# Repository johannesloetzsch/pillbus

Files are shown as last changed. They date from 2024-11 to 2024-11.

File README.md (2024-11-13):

## [PillBus](./hw/stm32)

## License

This source describes Open Hardware and is licensed under the [CERN-OHL-S v2](https://ohwr.org/cern_ohl_s_v2.txt)

Should you produce hardware based on this source, you must where practicable maintain the source location visible on the external case of the products.

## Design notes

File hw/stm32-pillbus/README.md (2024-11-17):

# PillBus

Simple and configurable bus controllers based on STM32.

## [STM32F103C8T6](https://www.lcsc.com/datasheet/lcsc_datasheet_2302211130_STMicroelectronics-STM32F103C8T6_C8734.pdf)

Different from `OtterPill`, a newer MCU is used:

* ARM Cortex-M3
* 2V~3.6V Operating Voltage Range
* 50mA max current consumption (Run mode, 72MHz, all peripherals enabled)
* 64KB Program FLASH Storage
* 20KB RAM
* max 72MHz, Internal Oscillator
* 35/37 GPIO Ports
* 2 SPI, 2 I²C, 3 USART, 1 USB 2.0 full-speed, 1 CAN
* 12bit ADC
* DMA

[MCU pinout](./pinout.md)

### Rust

Examples on similar MCUs

* [blinky-rust-nix](https://github.com/johannesloetzsch/blinky-rust-nix)
* [jamesmunns OtterPill-rs](https://github.com/jamesmunns/OtterPill-rs)
* [Tock OS](https://github.com/tock)
* [LinuxM3](http://www.linux-arm.org/LinuxKernel/LinuxM3)

## Peripherals

### [WS2812B RGB-LEDs](https://wmsc.lcsc.com/wmsc/upload/file/pdf/v2/lcsc/2406131538_XINGLIGHT-XL-5050RGBC-WS2812B-S_C22461793.pdf)

* -0.5-5.5 V Supply Voltage
* 3.0-7.0 V Logic input Voltage
* 12 mA RGB output Current

## [Power supply via USB](https://en.wikipedia.org/wiki/USB_hardware#Allowable_current_draw)

| USB Specification | Current | Voltage | Configuration | usage |
| --- | --- | --- | --- | --- |
| USB 2.0 Low-power device  | 100mA | 5V | default | 1-2 MCU at max or 5 MCU at low consumption |
| USB 2.0 High-power device | 500mA | 5V | „Power Budgeting“ during device enumeration | 5 MCU at max + 16 RGB-LEDs |
| USB Battery Charging | 1.5 A | 5V | charger detection algorithm | 5 MCU at max + 96 RGB-LEDs |
| USB TypeC Power Delivery  | 3.0 A | 5V | PD IC | 5 MCU at max + ~200 RGB-LEDs |

### [USB Battery Charging](https://usb.org/sites/default/files/BCv1.2_070312_0.zip)

`Portable Devices` „with a Good Battery“ are required to implement the charger detection algorithm defined at [Battery Charging Specification section 3.3.2](https://usb.org/sites/default/files/BCv1.2_070312_0.zip)

#### Primary Detection

`Portable Devices` (PD) are required to implement `Primary Detection` to distinguish between `Standard Downstream Port` (SDP) and different types of `Charging Ports` (`Charging Downstream Port` (SDP) or `, `Dedicated Charging Port` (DCP)).

`Dedicated Charging Ports` are identified by `RDCP_DAT <= 200 Ω` between D+ and D−. The `Portable Device` sets D+ and tests on D- if a similar voltage is detected. 

`Charging Downstream Ports` are allowed to identify by either one of two ways:
1. D- is set within `TCP_VDM_EN` of a disconnect and then unset within `TCP_VDM_DIS` of a connect.
2. D- is set exactly when `VDAT_REF < D+ < VLGC`

`Accessory charging adapters` (ACA) exist for `USB On-The-Go` and have an additional detection mechanism.

#### Secondary Detection

Secondary Detection can be used to distinguish between DCP and CDP. Portable Devices that are ready to be enumerated are allowed to bypass Secondary Detection. Secondary Detection identifies `Dedicated Charging Ports` by `RDCP_DAT <= 200 Ω` between D+ and D−. The `Portable Device` sets D- and tests on D+ if a similar voltage is detected.

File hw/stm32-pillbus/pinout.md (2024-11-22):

## [STM32F103xx pin definitions](https://www.lcsc.com/datasheet/lcsc_datasheet_2302211130_STMicroelectronics-STM32F103C8T6_C8734.pdf)

| Protocol | Pin | Board | Dev | Port | IDE | Chip | Type | Level | Function | Alternate Remap |
| --- | ----- | ----- | ----- | ---- | --- | ---- | ---- | ----- | --- | --- |
| | | VBAT  | VBAT  | | | 1 | S | | VBAT | |
| | pc13  | | | D0 | 40  | 2 | I/O  | | PC13(6) | TAMPER-RTC |
| | pc14  | | | D1 | 38  | 3 | I/O  | | PC14(6) | OSC32_IN |
| | pc15  | | | D2 | 36  | 4 | I/O  | | PC15(6) | OSC32_OUT |
| | | | | | 34  | | | | | /* blue connector */ |
| | (pd0) | OSC_I | | | (-) | 5 | I | | OSC_IN | PD0(7) |
| | (pd1) | OSC_O | | | (-) | 6 | O | | OSC_OUT | PD1(7) |
| | | NRST  | NRST  | | (*) | 7 | I/O  | | NRST | |
| | | | | | | 8 | S | | VSSA | |
| | | | | | | 9 | S | | VDDA | |
| USART2_CTS | pa0 | ad0 | | D3 | 32  | 10 | I/O  | | PA0 | WKUP/USART2_CTS(9)/ADC12_IN0/TIM2_CH1_ETR(9) |
| USART2_RTS | pa1 | ad1 | | D4 | 30  | 11 | I/O  | | PA1 | USART2_RTS(9)/ADC12_IN1/TIM2_CH2(9) |
| | | | | | 28  | | | | | /* cable select */ |
| USART2_TX | pa2 | ad2 | | D5 | 26  | 12 | I/O  | | PA2 | USART2_TX(9)/ADC12_IN2/TIM2_CH3(9) |
| USART2_RX | pa3 | ad3 | | D6 | 24  | 13 | I/O  | | PA3 | USART2_RX(9)/ADC12_IN3/TIM2_CH4(9) |
| USART2_CK, SPI1_NSS | pa4 | ad4 | | D7 | 22  | 14 | I/O  | | PA4 | SPI1_NSS(9)/USART2_CK(9)/ADC12_IN4 |
| | | | | | 20  | | | | | /* mechanical key */ |
| SPI1_SCK | pa5 | ad5 | | B7 | 18  | 15 | I/O  | | PA5 | SPI1_SCK(9)/ADC12_IN5 |
| SPI1_MISO | pa6 | ad6 | | B6 | 16  | 16 | I/O  | | PA6 | SPI1_MISO(9)/ADC12_IN6/TIM3_CH1(9) TIM1_BKIN |
| SPI1_MOSI | pa7 | ad7 | | B5 | 14  | 17 | I/O  | | PA7 | SPI1_MOSI(9)/ADC12_IN7/TIM3_CH2(9) TIM1_CH1N |
| | pb0 | ad8 | | B4 | 12  | 18 | I/O  | | PB0 | ADC12_IN8/TIM3_CH3(9) TIM1_CH2N |
| | pb1 | ad9 | | B3 | 10  | 19 | I/O  | | PB1 | ADC12_IN9/TIM3_CH4(9) TIM1_CH3N |
| | PB2 | Boot1 | Boot1 | B2 | 8 | 20 | I/O  | FT | PB2/BOOT1  | |
| I2C2_SCL, USART3_TX | PB10  | | | B1 | 6 | 21 | I/O  | FT | PB10 | I2C2_SCL/USART3_TX(9) TIM2_CH3 |
| I2C2_SDA, USART3_RX | PB11  | | | B0 | 4 | 22 | I/O  | FT | PB11 | I2C2_SDA/USART3_RX(9) TIM2_CH4 |
| | | | | | 1 | 23 | S | | VSS_1 | |
| | | | | | 2 | 24 | S | | VDD_1 | |
| SPI2_NSS | PB12  | | | A7 | 5 | 25 | I/O  | FT | PB12 | SPI2_NSS/I2C2_SMBAl/USART3_CK(9)/TIM1_BKIN(9) |
| SPI2_SCK | PB13  | | | A6 | 7 | 26 | I/O  | FT | PB13 | SPI2_SCK/USART3_CTS(9)/TIM1_CH1N(9) |
| SPI2_MISO | PB14  | | | A5 | 9 | 27 | I/O  | FT | PB14 | SPI2_MISO/USART3_RTS(9) TIM1_CH2N(9) |
| SPI2_MOSI | PB15  | | | A4 | 11  | 28 | I/O  | FT | PB15 | SPI2_MOSI/TIM1_CH3N(9) |
| | PA8 | | | A3 | 13  | 29 | I/O  | FT | PA8 | USART1_CK/TIM1_CH1(9)/MCO |
| USART1_TX | PA9 | TX | TX | A2 | 15  | 30 | I/O  | FT | PA9 | USART1_TX(9)/TIM1_CH2(9) |
| USART1_RX | PA10  | RX | RX_ | A1 | 17  | 31 | I/O  | FT | PA10 | USART1_RX(9)/TIM1_CH3(9) |
| USBd-, CANRX | PA11  | USBd- | USBd- | A0 | 19  | 32 | I/O  | FT | PA11 | USART1_CTS/CANRX(9)/USBDM/TIM1_CH4(9) |
| USBd+, CANRX | PA12  | USBd+ | USBd+ | C0 | 21  | 33 | I/O  | FT | PA12 | USART1_RTS/CANTX(9)/USBDP/TIM1_ETR(9) |
| | PA13  | SWDIO | SWDIO | C1 | 23  | 34 | I/O  | FT | JTMS/SWDIO | PA13 |
| | | | | | | 35 | S | | VSS_2 | |
| | | | | | | 36 | S | | VDD_2 | |
| | PA14  | SWCLK | SWCLK | C2 | 25  | 37 | I/O  | FT | JTCK/SWCLK | PA14 |
| SPI1_NSS | PA15  | | | C3 | 27  | 38 | I/O  | FT | JTDI | TIM2_CH1_ETR/PA15/SPI1_NSS |
| SPI1_SCK | PB3 | | | C4 | 29  | 39 | I/O  | FT | JTDO | TIM2_CH2/PB3 TRACESWO/SPI1_SCK |
| SPI1_MISO | PB4 | | | C5 | 31  | 40 | I/O  | FT | JNTRST | TIM3_CH1/PB4/SPI1_MISO |
| SPI1_MOSI | pb5 | | | C6 | 33  | 41 | I/O  | | PB5 | I2C1_SMBAl TIM3_CH2/SPI1_MOSI |
| | PB6 | | | C7 | 35  | 42 | I/O  | FT | PB6 | I2C1_SCL(9)/TIM4_CH1(9) USART1_TX |
| USB_VbusSense | PB7 | VbusS | | | 3 | 43 | I/O  | FT | PB7 | I2C1_SDA(9)/TIM4_CH2(9) USART1_RX |
| | | Boot0 | Boot0 | | (*) | 44 | I | | BOOT0 | |
| I2C1_SCL, CANRX | PB8 | SCL | SCL | SCL  | 37  | 45 | I/O  | FT | PB8 | TIM4_CH3(9) I2C1_SCL/CANRX |
| I2C1_SDA, CANTX | PB9 | SDA | SDA | SDA  | 39  | 46 | I/O  | FT | PB9 | TIM4_CH4(9) I2C1_SDA/CANTX |
| | | | | | | 47 | S | | VSS_3 | |
| | | | | | | 48 | S | | VDD_3 | |

Legend:
> Pin (digital): UPPER = 5 V tolerant
> Type: I = input, O = output, S = supply
> Level: FT = 5 V tolerant

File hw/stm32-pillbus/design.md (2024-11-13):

# Sources

* [Introduction to USB hardware and PCB guidelines using STM32 MCUs](https://www.st.com/resource/en/application_note/dm00296349-usb-hardware-and-pcb-guidelines-using-stm32-mcus-stmicroelectronics.pdf)
* [Guidelines for oscillator design](https://www.st.com/resource/en/application_note/cd00221665-oscillator-design-guide-for-stm8af-al-s-stm32-mcus-and-mpus-stmicroelectronics.pdf)

* [BluePill schematics](https://github.com/STM32-base/STM32-base.github.io/blob/master/assets/pdf/boards/original-schematic-STM32F103C8T6-Blue_Pill.pdf)

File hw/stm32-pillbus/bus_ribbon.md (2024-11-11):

# Ribbon cables

## [IDE (PATA)](https://en.wikipedia.org/wiki/Parallel_ATA#Interface)

ide cable

ide plug

footprint

37 of 40 Pins are direct wired.

Exceptions:
* Pin **20**: mechanical key -> no attached
* Pin **28**: cable select -> not attached on slave (middle), but at blue and master
* Pin **34**: not attached or ground at blue connector

## [FDD](https://en.wikipedia.org/wiki/Floppy_disk_drive_interface)

fdd cable

footprint

33 of 34 Pins should be usable. 6 Pins are twisted before last connector.

Exceptions:
* Pin **5**: mechanical key -> no attached
* Pins *3*, *4*, *6*: Reserved -> better check if attached
* Pins **10-16**: cable select -> twisted between first and second „drive“

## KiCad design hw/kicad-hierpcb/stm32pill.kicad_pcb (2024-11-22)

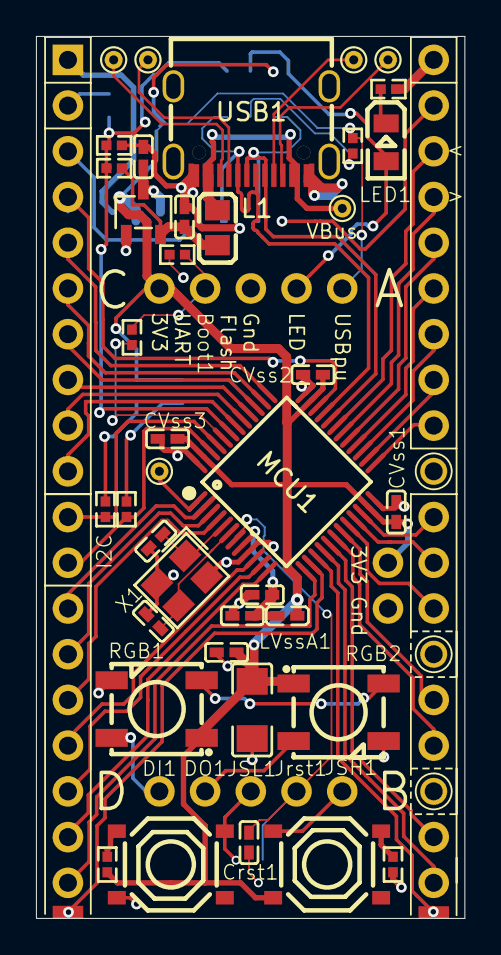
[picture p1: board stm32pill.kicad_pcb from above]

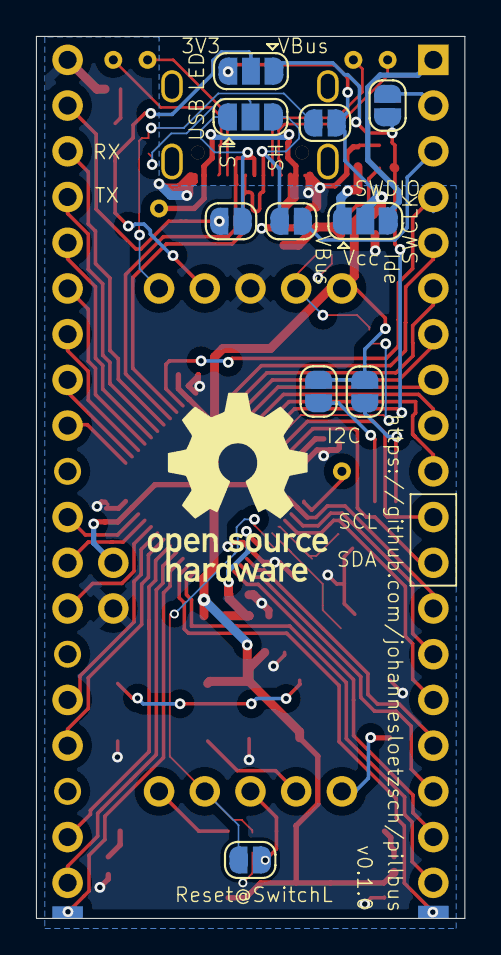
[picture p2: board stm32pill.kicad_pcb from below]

Board: 2 copper layers, 23.8 x 49.0 mm, 63 parts (10 on the bottom side), 68 nets.

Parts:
3.3V1: PTH 1.7mm
Boot1: 3x PTH 1.7mm
CC1_1, CC2_1: TestPoint_THTPad_D1.0mm_Drill0.5mm
CLed1: 100nF; C0402
CUin1: 1μF; C0402
CUout1: 1μF; C0402
CVcc1: 4.7uF; C1206
CVss1, CVss2, CVss3: 100nF; C0402
CVssA1: 1μF; C0402
CVssAn1: 10nF; C0402
Cosc1, Cosc2: 30pF; C0402
Crst1: 100nF; C0402
DI1: PTH 1.7mm
DO1: PTH 1.7mm
GND1: PTH 1.7mm
IDE_STM_A1: IDE STM A
IDE_STM_B1: IDE STM B cut
IDE_STM_C1: IDE STM C
IDE_STM_D1: IDE STM D cut
JPLed1: SolderJumper_3_Open; SolderJumper-3_P1.3mm_Open_RoundedPad1.0x1.5mm
JPReset1: SolderJumper_2_Open; SolderJumper-2_P1.3mm_Open_RoundedPad1.0x1.5mm
JPRscl1: SolderJumper_2_Open; SolderJumper-2_P1.3mm_Open_RoundedPad1.0x1.5mm
JPRsda1: SolderJumper_2_Open; SolderJumper-2_P1.3mm_Open_RoundedPad1.0x1.5mm
JPV1: SolderJumper_3_Open; SolderJumper-3_P1.3mm_Open_RoundedPad1.0x1.5mm
JPdn1: SolderJumper_2_Open; SolderJumper-2_P1.3mm_Open_RoundedPad1.0x1.5mm
JPdp1: SolderJumper_2_Open; SolderJumper-2_P1.3mm_Open_RoundedPad1.0x1.5mm
JPpuUSB1: SolderJumper_3_Open; SolderJumper-3_P1.3mm_Open_RoundedPad1.0x1.5mm
JPpuUSBconst1: SolderJumper_2_Open; SolderJumper-2_P1.3mm_Open_RoundedPad1.0x1.5mm
JPvbus1: SolderJumper_2_Open; SolderJumper-2_P1.3mm_Open_RoundedPad1.0x1.5mm
JSH1: PTH 1.7mm
JSL1: PTH 1.7mm
JVbat1: VBAT; TestPoint_THTPad_D1.0mm_Drill0.5mm
Jled1: PTH 1.7mm
JpuUSB1: PTH 1.7mm
Jrst1: PTH 1.7mm
L1: 100Ω@100MHz; L0805
LED1: Green; LED0805-R-RD
LVssA1: 15-30nH; L0402
MCU1: STM32F103C8T6; LQFP-48_L7.0-W7.0-P0.50-LS9.0-BL
RGB1, RGB2: LED WS2812B; LED-SMD_4P-L5.0-W5.0-TL-1
RSBoot1: 51kΩ; R0402
RVbusI1: 51kΩ; R0402
RVbusO1: 100kΩ; R0402
Rled1: 1k-1.5k; R0402
Rpd1: 10kΩ; R0402
Rpu1: 10kΩ; R0402
RpuBoot1: 51kΩ; R0402
RpuUSB1: 1.5kΩ; R0402
Rscl1: 2.2kΩ; R0402
Rsda1: 2.2kΩ; R0402
SBU1_1, SBU2_1: TestPoint_THTPad_D1.0mm_Drill0.5mm
SW1, SW2: Tactile Switch; SW-SMD_4P-L5.1-W5.1-P3.70-LS6.5-TL_H1.5
U1: 3.3V Voltage Regulator 200mA; SOT-23-3_L2.9-W1.6-P1.90-LS2.8-BR
USB1: USB_C; USB-C_SMD-TYPE-C-31-M-12
VBus_1: TestPoint_THTPad_D1.0mm_Drill0.5mm
X1: Crystal 12MHz X322512MSB4SI; CRYSTAL-SMD_4P-L3.2-W2.5-BL

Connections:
+3.3V: 3.3V1.1, Boot1.3, CLed1.2, CVcc1.1, CVss1.2, CVss2.2, CVss3.2, JPLed1.3 (B), JPRscl1.2 (B), JPRsda1.1 (A), JPV1.2 (C), JPpuUSBconst1.2 (B), LVssA1.2, MCU1.23 (VSS_1), MCU1.35 (VSS_2), MCU1.47 (VSS_3), RGB1.1 (VDD), RGB2.1 (VDD), Rpu1.2, SW2.2 (B)
/Boot0: Boot1.2, RSBoot1.2, RpuBoot1.1
/CC1: CC1_1.1, USB1.A5 (CC1)
/CC2: CC2_1.1, USB1.B5 (CC2)
/I2C1 SCL: IDE_STM_D1.SCL (IDE39_STM45), MCU1.45 (PB8), Rscl1.1
/I2C1 SDA: IDE_STM_D1.SDA (IDE37_STM46), MCU1.46 (PB9), Rsda1.1
/I2C2 SCL, USART3 TX: IDE_STM_B1.B1 (IDE24_STM13), MCU1.21 (PB10)
/I2C2 SDA, USART3 RX: IDE_STM_B1.B0 (IDE22_STM14), MCU1.22 (PB11)
/NRST: Crst1.2, JPReset1.1 (A), Jrst1.1, MCU1.7 (NRST)
/OSC_IN: Cosc1.2, MCU1.5 (PD0-OSC_IN), X1.1 (OSC1)
/OSC_OUT: Cosc2.2, MCU1.6 (PD1-OSC_OUT), X1.3 (OSC2)
/SBU1: SBU1_1.1, USB1.A8 (SBU1)
/SBU2: SBU2_1.1, USB1.B8 (SBU2)
/SPI1 MISO: IDE_STM_B1.B6 (IDE38_STM3), MCU1.16 (PA6)
/SPI1 MOSI: IDE_STM_B1.B5 (IDE36_STM4), MCU1.17 (PA7)
/SPI1 SCK: IDE_STM_B1.B7 (IDE40_STM2), MCU1.15 (PA5)
/SPI2 MISO: IDE_STM_A1.A5 (IDE14_STM17), MCU1.27 (PB14)
/SPI2 MOSI: IDE_STM_A1.A4 (IDE12_STM18), MCU1.28 (PB15)
/SPI2 NSS: IDE_STM_A1.A7 (IDE18_STM15), MCU1.25 (PB12)
/SPI2 SCK: IDE_STM_A1.A6 (IDE16_STM16), MCU1.26 (PB13)
/USART1 RX: IDE_STM_A1.A1 (IDE6_STM21), MCU1.31 (PA10)
/USART1 TX: IDE_STM_A1.A2 (IDE8_STM20), MCU1.30 (PA9)
/USB VBusSense: JPLed1.1 (A), JPvbus1.1 (A), MCU1.43 (PB7), RVbusI1.2, RVbusO1.1
/USBd+: JPdp1.2 (B), JPpuUSB1.3 (B), MCU1.33 (PA12), USB1.A6 (DP1), USB1.B6 (DP2)
/USBd-: JPdn1.1 (A), JPpuUSB1.1 (A), MCU1.32 (PA11), USB1.A7 (DN1), USB1.B7 (DN2)
/VBAT: JVbat1.1, MCU1.1 (VBAT)
/VBUS: CUin1.1, L1.1, RVbusI1.1, U1.2 (Vin)
/VSSA: CVssA1.2, CVssAn1.2, LVssA1.1, MCU1.8 (VSSA)
GND: Boot1.1, CLed1.1, CUin1.2, CUout1.2, CVcc1.2, CVss1.1, CVss2.1, CVss3.1, CVssA1.1, CVssAn1.1, Cosc1.1, Cosc2.1, Crst1.1, GND1.1, IDE_STM_A1.GND (IDE2_STM24), MCU1.9 (VDDA), MCU1.24 (VDD_1), MCU1.36 (VDD_2), MCU1.48 (VDD_3), RGB1.3 (GND), RGB2.3 (GND), RVbusO1.2, Rled1.1, Rpd1.1, RpuBoot1.2, SW1.3 (C), U1.1 (GND), USB1.A1 (GND), USB1.A12 (GND), USB1.B1 (GND), USB1.B12 (GND), X1.2 (GND), X1.4 (GND)
unnamed: DI1.1, RGB1.4 (DI)
unnamed: DO1.1, RGB2.2 (DO)
unnamed: IDE_STM_A1.A0 (IDE4_STM22), JPdn1.2 (B)
unnamed: IDE_STM_A1.A3 (IDE10_STM19), MCU1.29 (PA8)
unnamed: IDE_STM_B1.B2 (IDE26_STM12), MCU1.20 (PB2)
unnamed: IDE_STM_B1.B3 (IDE30_STM11), MCU1.19 (PB1)
unnamed: IDE_STM_B1.B4 (IDE32_STM10), MCU1.18 (PB0)
unnamed: IDE_STM_C1.3V3 (IDE1_STM23), JPV1.3 (B)
unnamed: IDE_STM_C1.VBusSense (IDE3_STM43), JPvbus1.2 (B)
unnamed: IDE_STM_C1.C0 (IDE5_STM25), JPdp1.1 (A)
unnamed: IDE_STM_C1.C1 (IDE7_STM26), MCU1.34 (PA13)
unnamed: IDE_STM_C1.C2 (IDE9_STM27), MCU1.37 (PA14)
unnamed: IDE_STM_C1.C3 (IDE11_STM28), MCU1.38 (PA15)
unnamed: IDE_STM_C1.C4 (IDE13_STM29), MCU1.39 (PB3)
unnamed: IDE_STM_C1.C5 (IDE15_STM30), MCU1.40 (PB4)
unnamed: IDE_STM_C1.C6 (IDE17_STM31), MCU1.41 (PB5)
unnamed: IDE_STM_C1.C7 (IDE19_STM32), MCU1.42 (PB6)
unnamed: IDE_STM_D1.D7 (IDE21_STM33), MCU1.14 (PA4)
unnamed: IDE_STM_D1.D6 (IDE23_STM34), MCU1.13 (PA3)
unnamed: IDE_STM_D1.D5 (IDE25_STM37), MCU1.12 (PA2)
unnamed: IDE_STM_D1.D4 (IDE27_STM38), MCU1.11 (PA1)
unnamed: IDE_STM_D1.D3 (IDE29_STM39), MCU1.10 (PA0-WKUP)
unnamed: IDE_STM_D1.D2 (IDE31_STM40), MCU1.4 (PC15-OSC32_OUT)
unnamed: IDE_STM_D1.D1 (IDE33_STM41), MCU1.3 (PC14-OSC32_IN)
unnamed: IDE_STM_D1.D0 (IDE35_STM42), MCU1.2 (PC13-TAMPER-RTC)
unnamed: JPLed1.2 (C), Jled1.1, LED1.1 (A)
unnamed: JPReset1.2 (B), JSL1.1, SW1.2 (B)
unnamed: JPRscl1.1 (A), Rscl1.2
unnamed: JPRsda1.2 (B), Rsda1.2
unnamed: CUout1.1, JPV1.1 (A), U1.3 (Vout)
unnamed: JPpuUSB1.2 (C), RpuUSB1.1
unnamed: JPpuUSBconst1.1 (A), JpuUSB1.1, RpuUSB1.2
unnamed: JSH1.1, SW2.4 (D)
unnamed: LED1.2 (K), Rled1.2
unnamed: MCU1.44 (BOOT0), RSBoot1.1
unnamed: RGB1.2 (DO), RGB2.4 (DI)
unnamed: Rpu1.1, SW1.1 (A)
unnamed: Rpd1.2, SW2.3 (C)
unnamed: L1.2, USB1.A4 (VBUS), USB1.A9 (VBUS), USB1.B4 (VBUS), USB1.B9 (VBUS), VBus_1.1

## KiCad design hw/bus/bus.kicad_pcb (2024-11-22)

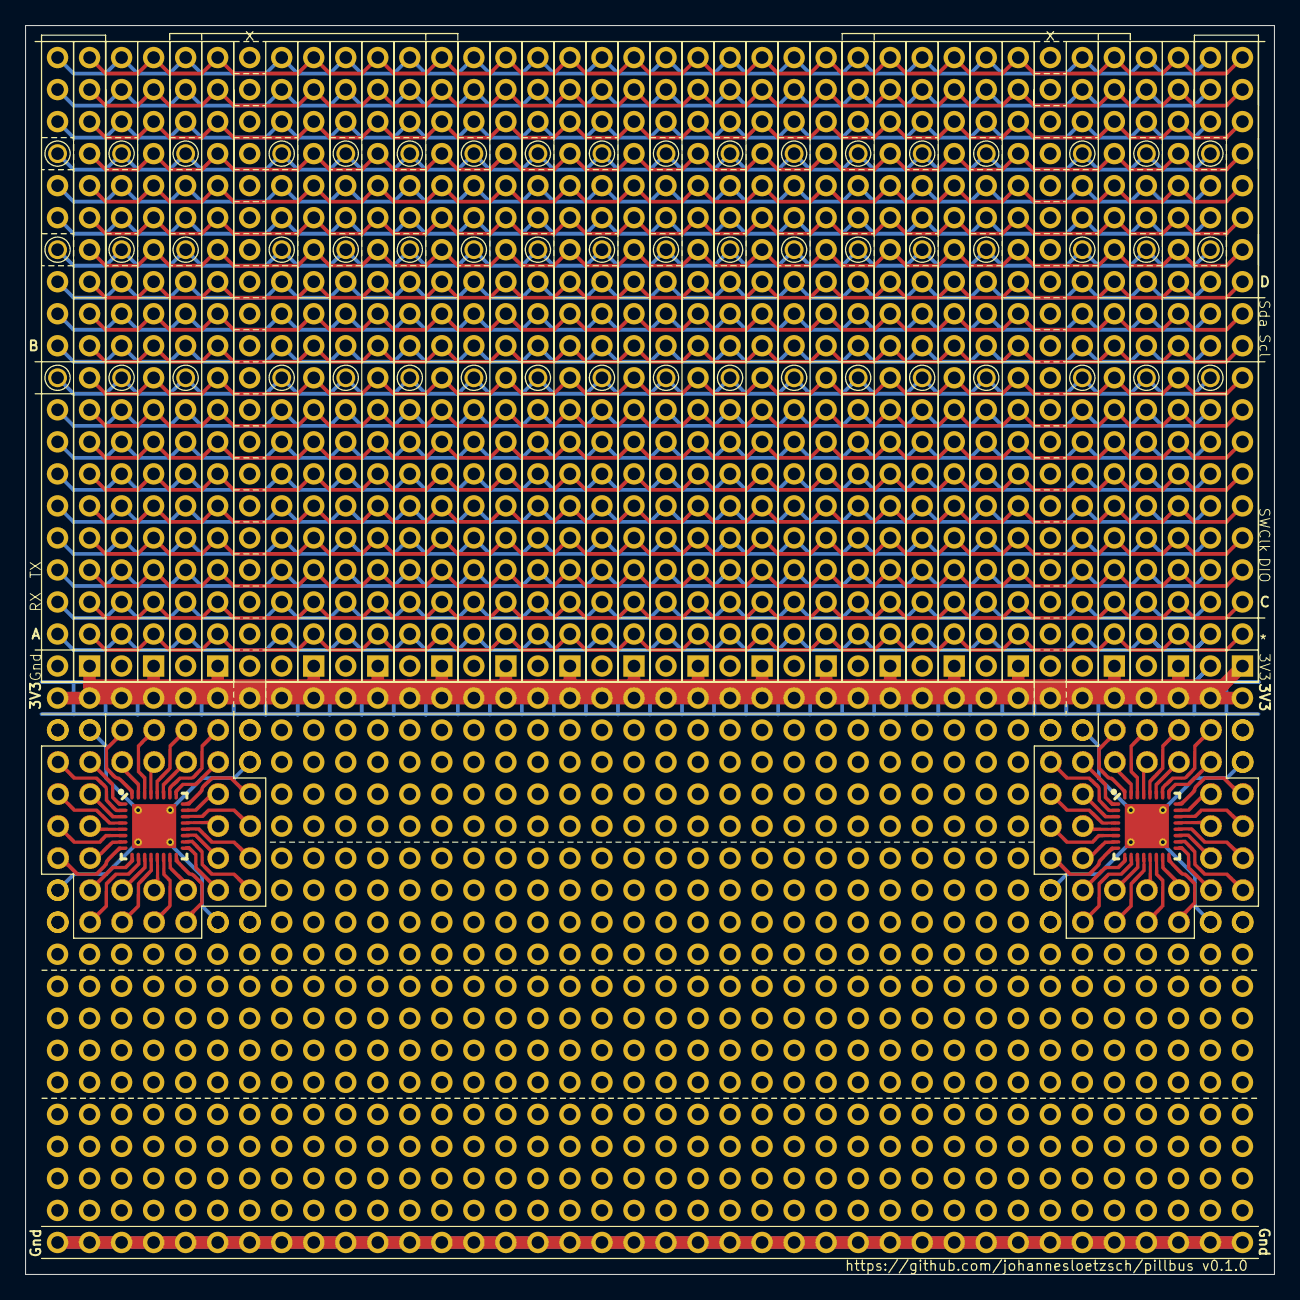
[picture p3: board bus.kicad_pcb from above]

Board: 2 copper layers, 99.1 x 99.1 mm, 58 parts (0 on the bottom side), 40 nets.

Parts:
Gnd1, Gnd2, Gnd3, Gnd4, Gnd5, Gnd6, Gnd7, Gnd8, Gnd9, Gnd10, Gnd11, Gnd12, Gnd13, Gnd14, Gnd15, Gnd16, Gnd17, Gnd18, Gnd19, Gnd20, Gnd21, Gnd22, Gnd23, Gnd24, Gnd25, Gnd26, Gnd27, Gnd28, Gnd29, Gnd30, Gnd31, Gnd32, Gnd33, Gnd34, Gnd35, Gnd36, Gnd37, Gnd38: PTH 1.7mm
J1, J2, J3, J4, J5, J6, J7, J11, J11#2, J11#3, J11#4, J11#5, J12, J13, J14, J15, J16, J17: IDE STM bus
U***: QFN-32; Breakout QFN-32
U***#2: QFN-32; Breakout QFN-32

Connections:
+3.3V: J1.3V3 (IDE1_STM23), J2.3V3 (IDE1_STM23), J3.3V3 (IDE1_STM23), J4.3V3 (IDE1_STM23), J5.3V3 (IDE1_STM23), J6.3V3 (IDE1_STM23), J7.3V3 (IDE1_STM23), J11.3V3 (IDE1_STM23), J11#2.3V3 (IDE1_STM23), J11#3.3V3 (IDE1_STM23), J11#4.3V3 (IDE1_STM23), J11#5.3V3 (IDE1_STM23), J12.3V3 (IDE1_STM23), J13.3V3 (IDE1_STM23), J14.3V3 (IDE1_STM23), J15.3V3 (IDE1_STM23), J16.3V3 (IDE1_STM23), J17.3V3 (IDE1_STM23)
/A0: J1.A0 (IDE4_STM22), J2.A0 (IDE4_STM22), J3.A0 (IDE4_STM22), J4.A0 (IDE4_STM22), J5.A0 (IDE4_STM22), J6.A0 (IDE4_STM22), J7.A0 (IDE4_STM22), J11.A0 (IDE4_STM22), J11#2.A0 (IDE4_STM22), J11#3.A0 (IDE4_STM22), J11#4.A0 (IDE4_STM22), J11#5.A0 (IDE4_STM22), J12.A0 (IDE4_STM22), J13.A0 (IDE4_STM22), J14.A0 (IDE4_STM22), J15.A0 (IDE4_STM22), J16.A0 (IDE4_STM22), J17.A0 (IDE4_STM22)
/A1: J1.A1 (IDE6_STM21), J2.A1 (IDE6_STM21), J3.A1 (IDE6_STM21), J4.A1 (IDE6_STM21), J5.A1 (IDE6_STM21), J6.A1 (IDE6_STM21), J7.A1 (IDE6_STM21), J11.A1 (IDE6_STM21), J11#2.A1 (IDE6_STM21), J11#3.A1 (IDE6_STM21), J11#4.A1 (IDE6_STM21), J11#5.A1 (IDE6_STM21), J12.A1 (IDE6_STM21), J13.A1 (IDE6_STM21), J14.A1 (IDE6_STM21), J15.A1 (IDE6_STM21), J16.A1 (IDE6_STM21), J17.A1 (IDE6_STM21)
/A2: J1.A2 (IDE8_STM20), J2.A2 (IDE8_STM20), J3.A2 (IDE8_STM20), J4.A2 (IDE8_STM20), J5.A2 (IDE8_STM20), J6.A2 (IDE8_STM20), J7.A2 (IDE8_STM20), J11.A2 (IDE8_STM20), J11#2.A2 (IDE8_STM20), J11#3.A2 (IDE8_STM20), J11#4.A2 (IDE8_STM20), J11#5.A2 (IDE8_STM20), J12.A2 (IDE8_STM20), J13.A2 (IDE8_STM20), J14.A2 (IDE8_STM20), J15.A2 (IDE8_STM20), J16.A2 (IDE8_STM20), J17.A2 (IDE8_STM20)
/A3: J1.A3 (IDE10_STM19), J2.A3 (IDE10_STM19), J3.A3 (IDE10_STM19), J4.A3 (IDE10_STM19), J5.A3 (IDE10_STM19), J6.A3 (IDE10_STM19), J7.A3 (IDE10_STM19), J11.A3 (IDE10_STM19), J11#2.A3 (IDE10_STM19), J11#3.A3 (IDE10_STM19), J11#4.A3 (IDE10_STM19), J11#5.A3 (IDE10_STM19), J12.A3 (IDE10_STM19), J13.A3 (IDE10_STM19), J14.A3 (IDE10_STM19), J15.A3 (IDE10_STM19), J16.A3 (IDE10_STM19), J17.A3 (IDE10_STM19)
/A4: J1.A4 (IDE12_STM18), J2.A4 (IDE12_STM18), J3.A4 (IDE12_STM18), J4.A4 (IDE12_STM18), J5.A4 (IDE12_STM18), J6.A4 (IDE12_STM18), J7.A4 (IDE12_STM18), J11.A4 (IDE12_STM18), J11#2.A4 (IDE12_STM18), J11#3.A4 (IDE12_STM18), J11#4.A4 (IDE12_STM18), J11#5.A4 (IDE12_STM18), J12.A4 (IDE12_STM18), J13.A4 (IDE12_STM18), J14.A4 (IDE12_STM18), J15.A4 (IDE12_STM18), J16.A4 (IDE12_STM18), J17.A4 (IDE12_STM18)
/A5: J1.A5 (IDE14_STM17), J2.A5 (IDE14_STM17), J3.A5 (IDE14_STM17), J4.A5 (IDE14_STM17), J5.A5 (IDE14_STM17), J6.A5 (IDE14_STM17), J7.A5 (IDE14_STM17), J11.A5 (IDE14_STM17), J11#2.A5 (IDE14_STM17), J11#3.A5 (IDE14_STM17), J11#4.A5 (IDE14_STM17), J11#5.A5 (IDE14_STM17), J12.A5 (IDE14_STM17), J13.A5 (IDE14_STM17), J14.A5 (IDE14_STM17), J15.A5 (IDE14_STM17), J16.A5 (IDE14_STM17), J17.A5 (IDE14_STM17)
/A6: J1.A6 (IDE16_STM16), J2.A6 (IDE16_STM16), J3.A6 (IDE16_STM16), J4.A6 (IDE16_STM16), J5.A6 (IDE16_STM16), J6.A6 (IDE16_STM16), J7.A6 (IDE16_STM16), J11.A6 (IDE16_STM16), J11#2.A6 (IDE16_STM16), J11#3.A6 (IDE16_STM16), J11#4.A6 (IDE16_STM16), J11#5.A6 (IDE16_STM16), J12.A6 (IDE16_STM16), J13.A6 (IDE16_STM16), J14.A6 (IDE16_STM16), J15.A6 (IDE16_STM16), J16.A6 (IDE16_STM16), J17.A6 (IDE16_STM16)
/A7: J1.A7 (IDE18_STM15), J2.A7 (IDE18_STM15), J3.A7 (IDE18_STM15), J4.A7 (IDE18_STM15), J5.A7 (IDE18_STM15), J6.A7 (IDE18_STM15), J7.A7 (IDE18_STM15), J11.A7 (IDE18_STM15), J11#2.A7 (IDE18_STM15), J11#3.A7 (IDE18_STM15), J11#4.A7 (IDE18_STM15), J11#5.A7 (IDE18_STM15), J12.A7 (IDE18_STM15), J13.A7 (IDE18_STM15), J14.A7 (IDE18_STM15), J15.A7 (IDE18_STM15), J16.A7 (IDE18_STM15), J17.A7 (IDE18_STM15)
/B0: J1.B0 (IDE22_STM14), J2.B0 (IDE22_STM14), J3.B0 (IDE22_STM14), J4.B0 (IDE22_STM14), J5.B0 (IDE22_STM14), J6.B0 (IDE22_STM14), J7.B0 (IDE22_STM14), J11.B0 (IDE22_STM14), J11#2.B0 (IDE22_STM14), J11#3.B0 (IDE22_STM14), J11#4.B0 (IDE22_STM14), J11#5.B0 (IDE22_STM14), J12.B0 (IDE22_STM14), J13.B0 (IDE22_STM14), J14.B0 (IDE22_STM14), J15.B0 (IDE22_STM14), J16.B0 (IDE22_STM14), J17.B0 (IDE22_STM14)
/B1: J1.B1 (IDE24_STM13), J2.B1 (IDE24_STM13), J3.B1 (IDE24_STM13), J4.B1 (IDE24_STM13), J5.B1 (IDE24_STM13), J6.B1 (IDE24_STM13), J7.B1 (IDE24_STM13), J11.B1 (IDE24_STM13), J11#2.B1 (IDE24_STM13), J11#3.B1 (IDE24_STM13), J11#4.B1 (IDE24_STM13), J11#5.B1 (IDE24_STM13), J12.B1 (IDE24_STM13), J13.B1 (IDE24_STM13), J14.B1 (IDE24_STM13), J15.B1 (IDE24_STM13), J16.B1 (IDE24_STM13), J17.B1 (IDE24_STM13)
/B2: J1.B2 (IDE26_STM12), J2.B2 (IDE26_STM12), J3.B2 (IDE26_STM12), J4.B2 (IDE26_STM12), J5.B2 (IDE26_STM12), J6.B2 (IDE26_STM12), J7.B2 (IDE26_STM12), J11.B2 (IDE26_STM12), J11#2.B2 (IDE26_STM12), J11#3.B2 (IDE26_STM12), J11#4.B2 (IDE26_STM12), J11#5.B2 (IDE26_STM12), J12.B2 (IDE26_STM12), J13.B2 (IDE26_STM12), J14.B2 (IDE26_STM12), J15.B2 (IDE26_STM12), J16.B2 (IDE26_STM12), J17.B2 (IDE26_STM12)
/B3: J1.B3 (IDE30_STM11), J2.B3 (IDE30_STM11), J3.B3 (IDE30_STM11), J4.B3 (IDE30_STM11), J5.B3 (IDE30_STM11), J6.B3 (IDE30_STM11), J7.B3 (IDE30_STM11), J11.B3 (IDE30_STM11), J11#2.B3 (IDE30_STM11), J11#3.B3 (IDE30_STM11), J11#4.B3 (IDE30_STM11), J11#5.B3 (IDE30_STM11), J12.B3 (IDE30_STM11), J13.B3 (IDE30_STM11), J14.B3 (IDE30_STM11), J15.B3 (IDE30_STM11), J16.B3 (IDE30_STM11), J17.B3 (IDE30_STM11)
/B4: J1.B4 (IDE32_STM10), J2.B4 (IDE32_STM10), J3.B4 (IDE32_STM10), J4.B4 (IDE32_STM10), J5.B4 (IDE32_STM10), J6.B4 (IDE32_STM10), J7.B4 (IDE32_STM10), J11.B4 (IDE32_STM10), J11#2.B4 (IDE32_STM10), J11#3.B4 (IDE32_STM10), J11#4.B4 (IDE32_STM10), J11#5.B4 (IDE32_STM10), J12.B4 (IDE32_STM10), J13.B4 (IDE32_STM10), J14.B4 (IDE32_STM10), J15.B4 (IDE32_STM10), J16.B4 (IDE32_STM10), J17.B4 (IDE32_STM10)
/B5: J1.B5 (IDE36_STM4), J2.B5 (IDE36_STM4), J3.B5 (IDE36_STM4), J4.B5 (IDE36_STM4), J5.B5 (IDE36_STM4), J6.B5 (IDE36_STM4), J7.B5 (IDE36_STM4), J11.B5 (IDE36_STM4), J11#2.B5 (IDE36_STM4), J11#3.B5 (IDE36_STM4), J11#4.B5 (IDE36_STM4), J11#5.B5 (IDE36_STM4), J12.B5 (IDE36_STM4), J13.B5 (IDE36_STM4), J14.B5 (IDE36_STM4), J15.B5 (IDE36_STM4), J16.B5 (IDE36_STM4), J17.B5 (IDE36_STM4)
/B6: J1.B6 (IDE38_STM3), J2.B6 (IDE38_STM3), J3.B6 (IDE38_STM3), J4.B6 (IDE38_STM3), J5.B6 (IDE38_STM3), J6.B6 (IDE38_STM3), J7.B6 (IDE38_STM3), J11.B6 (IDE38_STM3), J11#2.B6 (IDE38_STM3), J11#3.B6 (IDE38_STM3), J11#4.B6 (IDE38_STM3), J11#5.B6 (IDE38_STM3), J12.B6 (IDE38_STM3), J13.B6 (IDE38_STM3), J14.B6 (IDE38_STM3), J15.B6 (IDE38_STM3), J16.B6 (IDE38_STM3), J17.B6 (IDE38_STM3)
/B7: J1.B7 (IDE40_STM2), J2.B7 (IDE40_STM2), J3.B7 (IDE40_STM2), J4.B7 (IDE40_STM2), J5.B7 (IDE40_STM2), J6.B7 (IDE40_STM2), J7.B7 (IDE40_STM2), J11.B7 (IDE40_STM2), J11#2.B7 (IDE40_STM2), J11#3.B7 (IDE40_STM2), J11#4.B7 (IDE40_STM2), J11#5.B7 (IDE40_STM2), J12.B7 (IDE40_STM2), J13.B7 (IDE40_STM2), J14.B7 (IDE40_STM2), J15.B7 (IDE40_STM2), J16.B7 (IDE40_STM2), J17.B7 (IDE40_STM2)
/C0: J1.C0 (IDE5_STM25), J2.C0 (IDE5_STM25), J3.C0 (IDE5_STM25), J4.C0 (IDE5_STM25), J5.C0 (IDE5_STM25), J6.C0 (IDE5_STM25), J7.C0 (IDE5_STM25), J11.C0 (IDE5_STM25), J11#2.C0 (IDE5_STM25), J11#3.C0 (IDE5_STM25), J11#4.C0 (IDE5_STM25), J11#5.C0 (IDE5_STM25), J12.C0 (IDE5_STM25), J13.C0 (IDE5_STM25), J14.C0 (IDE5_STM25), J15.C0 (IDE5_STM25), J16.C0 (IDE5_STM25), J17.C0 (IDE5_STM25)
/C1: J1.C1 (IDE7_STM26), J2.C1 (IDE7_STM26), J3.C1 (IDE7_STM26), J4.C1 (IDE7_STM26), J5.C1 (IDE7_STM26), J6.C1 (IDE7_STM26), J7.C1 (IDE7_STM26), J11.C1 (IDE7_STM26), J11#2.C1 (IDE7_STM26), J11#3.C1 (IDE7_STM26), J11#4.C1 (IDE7_STM26), J11#5.C1 (IDE7_STM26), J12.C1 (IDE7_STM26), J13.C1 (IDE7_STM26), J14.C1 (IDE7_STM26), J15.C1 (IDE7_STM26), J16.C1 (IDE7_STM26), J17.C1 (IDE7_STM26)
/C2: J1.C2 (IDE9_STM27), J2.C2 (IDE9_STM27), J3.C2 (IDE9_STM27), J4.C2 (IDE9_STM27), J5.C2 (IDE9_STM27), J6.C2 (IDE9_STM27), J7.C2 (IDE9_STM27), J11.C2 (IDE9_STM27), J11#2.C2 (IDE9_STM27), J11#3.C2 (IDE9_STM27), J11#4.C2 (IDE9_STM27), J11#5.C2 (IDE9_STM27), J12.C2 (IDE9_STM27), J13.C2 (IDE9_STM27), J14.C2 (IDE9_STM27), J15.C2 (IDE9_STM27), J16.C2 (IDE9_STM27), J17.C2 (IDE9_STM27)
/C3: J1.C3 (IDE11_STM28), J2.C3 (IDE11_STM28), J3.C3 (IDE11_STM28), J4.C3 (IDE11_STM28), J5.C3 (IDE11_STM28), J6.C3 (IDE11_STM28), J7.C3 (IDE11_STM28), J11.C3 (IDE11_STM28), J11#2.C3 (IDE11_STM28), J11#3.C3 (IDE11_STM28), J11#4.C3 (IDE11_STM28), J11#5.C3 (IDE11_STM28), J12.C3 (IDE11_STM28), J13.C3 (IDE11_STM28), J14.C3 (IDE11_STM28), J15.C3 (IDE11_STM28), J16.C3 (IDE11_STM28), J17.C3 (IDE11_STM28)
/C4: J1.C4 (IDE13_STM29), J2.C4 (IDE13_STM29), J3.C4 (IDE13_STM29), J4.C4 (IDE13_STM29), J5.C4 (IDE13_STM29), J6.C4 (IDE13_STM29), J7.C4 (IDE13_STM29), J11.C4 (IDE13_STM29), J11#2.C4 (IDE13_STM29), J11#3.C4 (IDE13_STM29), J11#4.C4 (IDE13_STM29), J11#5.C4 (IDE13_STM29), J12.C4 (IDE13_STM29), J13.C4 (IDE13_STM29), J14.C4 (IDE13_STM29), J15.C4 (IDE13_STM29), J16.C4 (IDE13_STM29), J17.C4 (IDE13_STM29)
/C5: J1.C5 (IDE15_STM30), J2.C5 (IDE15_STM30), J3.C5 (IDE15_STM30), J4.C5 (IDE15_STM30), J5.C5 (IDE15_STM30), J6.C5 (IDE15_STM30), J7.C5 (IDE15_STM30), J11.C5 (IDE15_STM30), J11#2.C5 (IDE15_STM30), J11#3.C5 (IDE15_STM30), J11#4.C5 (IDE15_STM30), J11#5.C5 (IDE15_STM30), J12.C5 (IDE15_STM30), J13.C5 (IDE15_STM30), J14.C5 (IDE15_STM30), J15.C5 (IDE15_STM30), J16.C5 (IDE15_STM30), J17.C5 (IDE15_STM30)
/C6: J1.C6 (IDE17_STM31), J2.C6 (IDE17_STM31), J3.C6 (IDE17_STM31), J4.C6 (IDE17_STM31), J5.C6 (IDE17_STM31), J6.C6 (IDE17_STM31), J7.C6 (IDE17_STM31), J11.C6 (IDE17_STM31), J11#2.C6 (IDE17_STM31), J11#3.C6 (IDE17_STM31), J11#4.C6 (IDE17_STM31), J11#5.C6 (IDE17_STM31), J12.C6 (IDE17_STM31), J13.C6 (IDE17_STM31), J14.C6 (IDE17_STM31), J15.C6 (IDE17_STM31), J16.C6 (IDE17_STM31), J17.C6 (IDE17_STM31)
/C7: J1.C7 (IDE19_STM32), J2.C7 (IDE19_STM32), J3.C7 (IDE19_STM32), J4.C7 (IDE19_STM32), J5.C7 (IDE19_STM32), J6.C7 (IDE19_STM32), J7.C7 (IDE19_STM32), J11.C7 (IDE19_STM32), J11#2.C7 (IDE19_STM32), J11#3.C7 (IDE19_STM32), J11#4.C7 (IDE19_STM32), J11#5.C7 (IDE19_STM32), J12.C7 (IDE19_STM32), J13.C7 (IDE19_STM32), J14.C7 (IDE19_STM32), J15.C7 (IDE19_STM32), J16.C7 (IDE19_STM32), J17.C7 (IDE19_STM32)
/D0: J1.D0 (IDE35_STM42), J2.D0 (IDE35_STM42), J3.D0 (IDE35_STM42), J4.D0 (IDE35_STM42), J5.D0 (IDE35_STM42), J6.D0 (IDE35_STM42), J7.D0 (IDE35_STM42), J11.D0 (IDE35_STM42), J11#2.D0 (IDE35_STM42), J11#3.D0 (IDE35_STM42), J11#4.D0 (IDE35_STM42), J11#5.D0 (IDE35_STM42), J12.D0 (IDE35_STM42), J13.D0 (IDE35_STM42), J14.D0 (IDE35_STM42), J15.D0 (IDE35_STM42), J16.D0 (IDE35_STM42), J17.D0 (IDE35_STM42)
/D1: J1.D1 (IDE33_STM41), J2.D1 (IDE33_STM41), J3.D1 (IDE33_STM41), J4.D1 (IDE33_STM41), J5.D1 (IDE33_STM41), J6.D1 (IDE33_STM41), J7.D1 (IDE33_STM41), J11.D1 (IDE33_STM41), J11#2.D1 (IDE33_STM41), J11#3.D1 (IDE33_STM41), J11#4.D1 (IDE33_STM41), J11#5.D1 (IDE33_STM41), J12.D1 (IDE33_STM41), J13.D1 (IDE33_STM41), J14.D1 (IDE33_STM41), J15.D1 (IDE33_STM41), J16.D1 (IDE33_STM41), J17.D1 (IDE33_STM41)
/D2: J1.D2 (IDE31_STM40), J2.D2 (IDE31_STM40), J3.D2 (IDE31_STM40), J4.D2 (IDE31_STM40), J5.D2 (IDE31_STM40), J6.D2 (IDE31_STM40), J7.D2 (IDE31_STM40), J11.D2 (IDE31_STM40), J11#2.D2 (IDE31_STM40), J11#3.D2 (IDE31_STM40), J11#4.D2 (IDE31_STM40), J11#5.D2 (IDE31_STM40), J12.D2 (IDE31_STM40), J13.D2 (IDE31_STM40), J14.D2 (IDE31_STM40), J15.D2 (IDE31_STM40), J16.D2 (IDE31_STM40), J17.D2 (IDE31_STM40)
/D3: J1.D3 (IDE29_STM39), J2.D3 (IDE29_STM39), J3.D3 (IDE29_STM39), J4.D3 (IDE29_STM39), J5.D3 (IDE29_STM39), J6.D3 (IDE29_STM39), J7.D3 (IDE29_STM39), J11.D3 (IDE29_STM39), J11#2.D3 (IDE29_STM39), J11#3.D3 (IDE29_STM39), J11#4.D3 (IDE29_STM39), J11#5.D3 (IDE29_STM39), J12.D3 (IDE29_STM39), J13.D3 (IDE29_STM39), J14.D3 (IDE29_STM39), J15.D3 (IDE29_STM39), J16.D3 (IDE29_STM39), J17.D3 (IDE29_STM39)
/D4: J1.D4 (IDE27_STM38), J2.D4 (IDE27_STM38), J3.D4 (IDE27_STM38), J4.D4 (IDE27_STM38), J5.D4 (IDE27_STM38), J6.D4 (IDE27_STM38), J7.D4 (IDE27_STM38), J11.D4 (IDE27_STM38), J11#2.D4 (IDE27_STM38), J11#3.D4 (IDE27_STM38), J11#4.D4 (IDE27_STM38), J11#5.D4 (IDE27_STM38), J12.D4 (IDE27_STM38), J13.D4 (IDE27_STM38), J14.D4 (IDE27_STM38), J15.D4 (IDE27_STM38), J16.D4 (IDE27_STM38), J17.D4 (IDE27_STM38)
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

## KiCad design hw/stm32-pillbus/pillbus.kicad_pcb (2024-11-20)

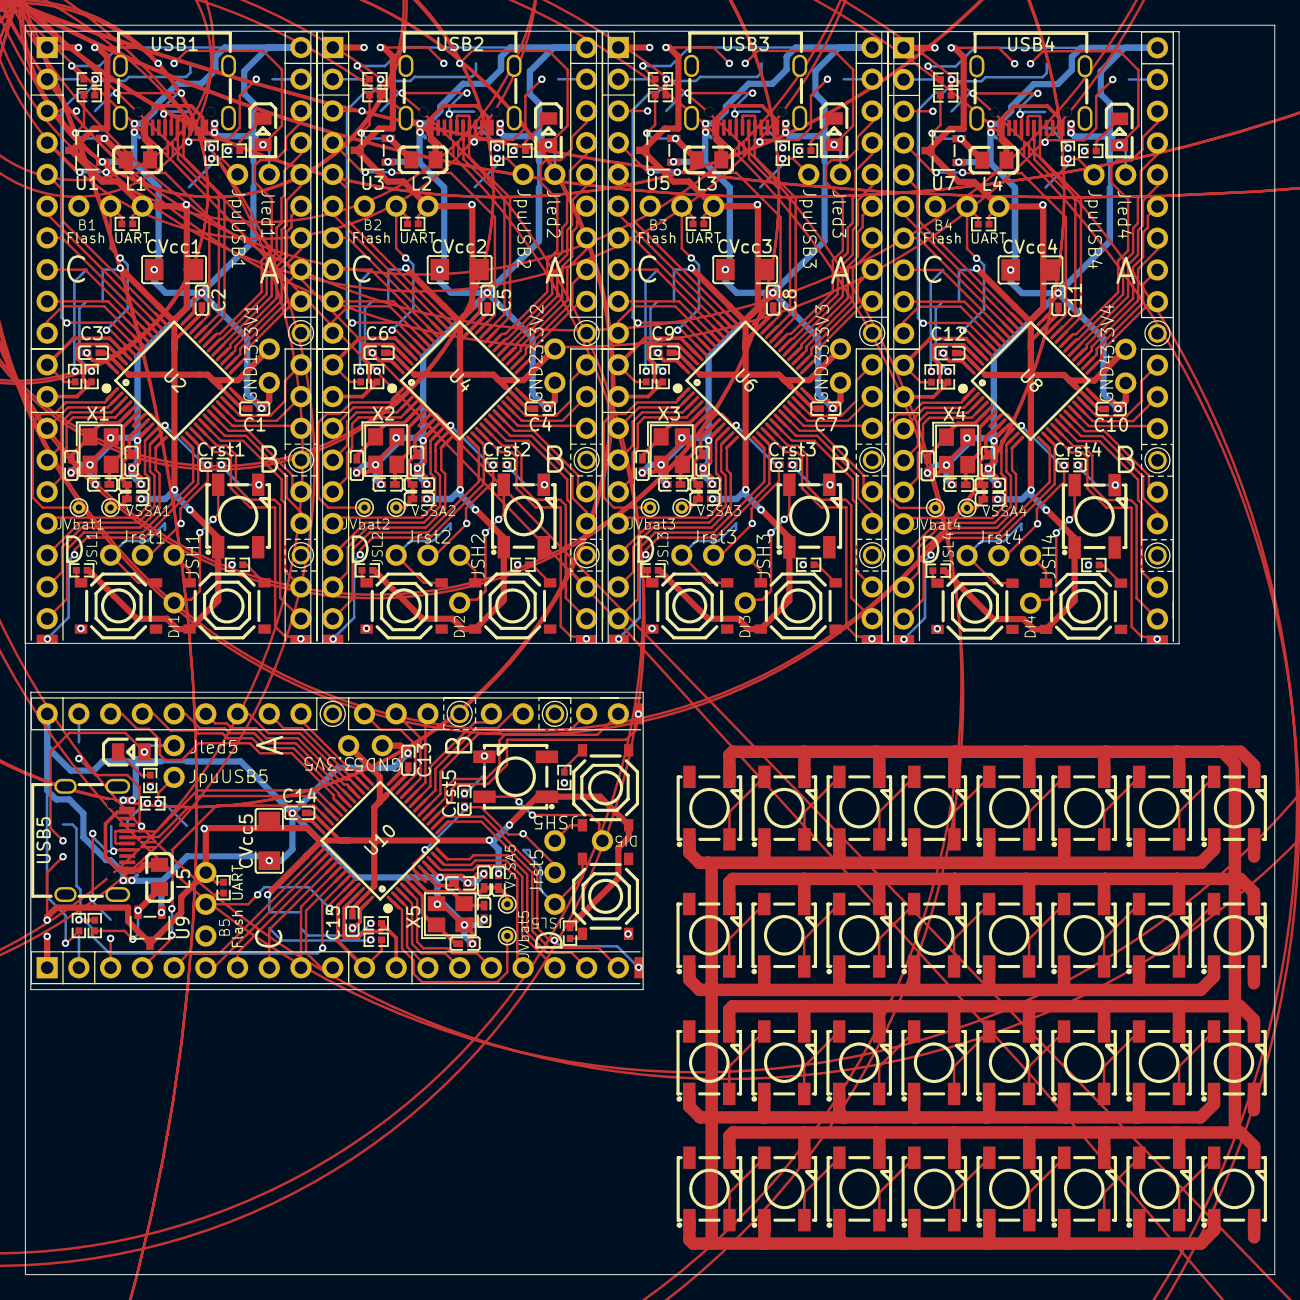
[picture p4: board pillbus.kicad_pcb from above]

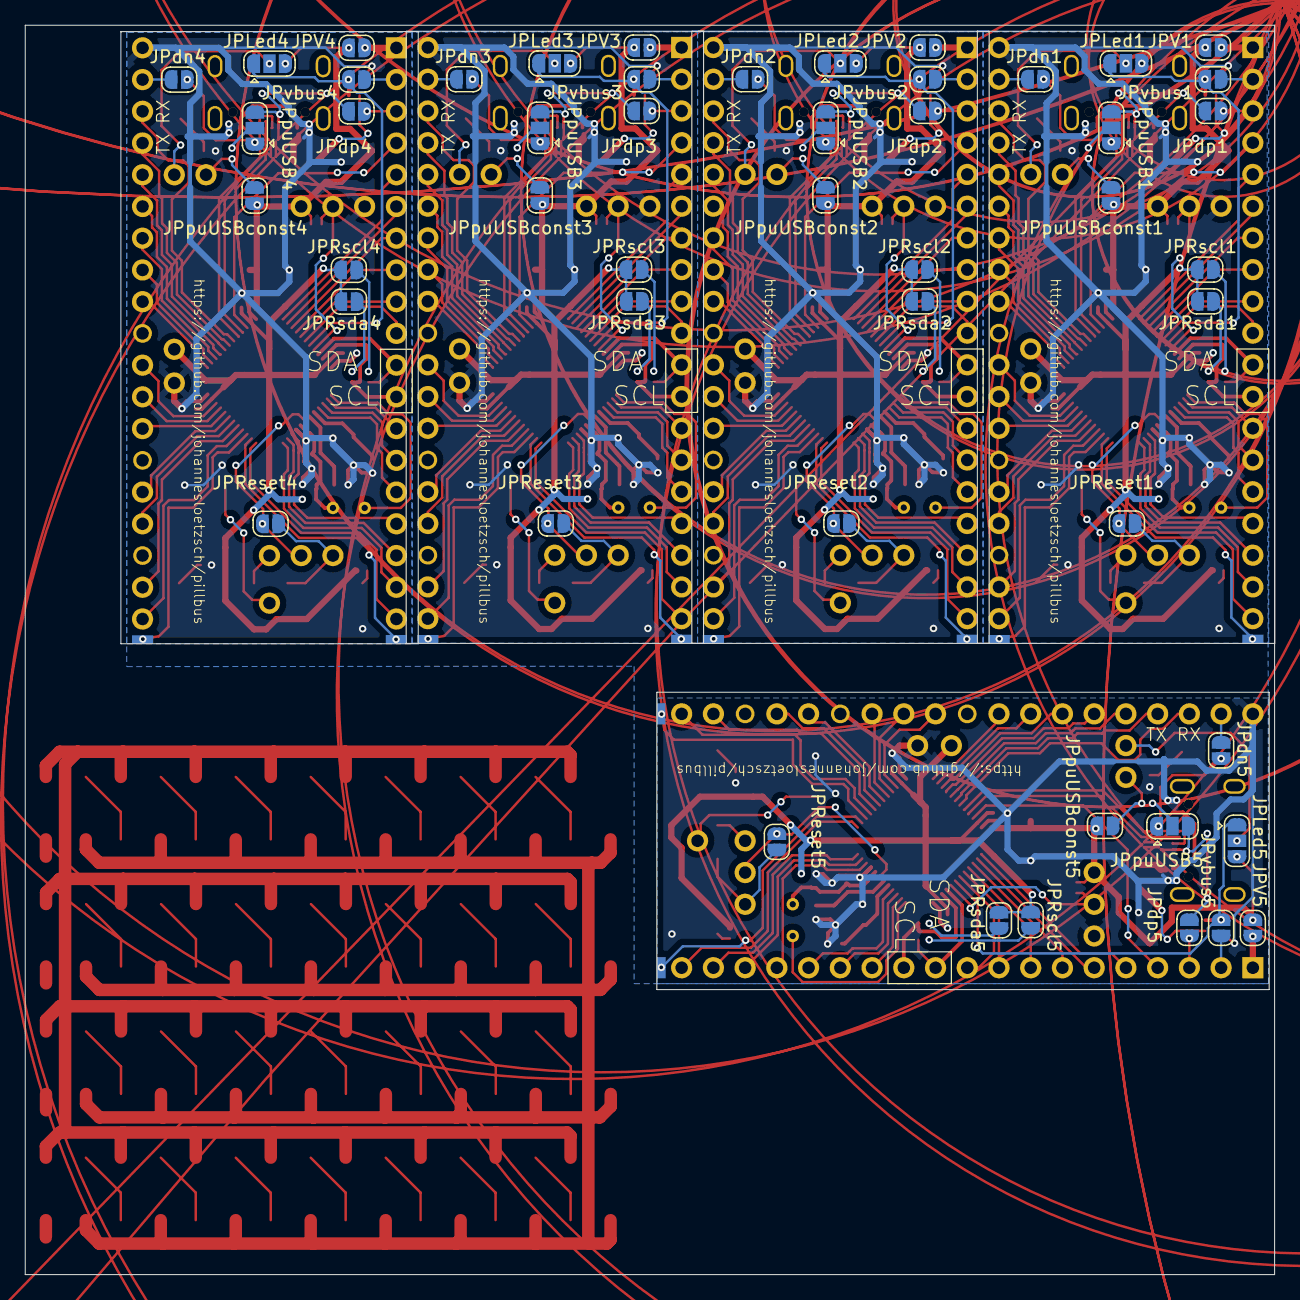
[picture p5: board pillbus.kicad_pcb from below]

Board: 2 copper layers, 100.0 x 100.0 mm, 297 parts (50 on the bottom side), 320 nets.

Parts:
3.3V1, 3.3V2, 3.3V3, 3.3V4, 3.3V5: PTH 1.7mm
B1, B2, B3, B4, B5: 3x PTH 1.7mm
C1, C2, C3, C4, C5, C6, C7, C8, C9, C10, C11, C12, C13, C14, C15: 100nF; C0402
CVcc1, CVcc2, CVcc3, CVcc4, CVcc5: 4.7uF; C1206
CVssA1, CVssA2, CVssA3, CVssA4, CVssA5: 1μF; C0402
CVssAn1, CVssAn2, CVssAn3, CVssAn4, CVssAn5: 10nF; C0402
Cosc1, Cosc2, Cosc3, Cosc4, Cosc5, Cosc6, Cosc7, Cosc8, Cosc9, Cosc10: 30pF; C0402
Crst1, Crst2, Crst3, Crst4, Crst5: 100nF; C0402
DI1, DI2, DI3, DI4, DI5: PTH 1.7mm
GND1, GND2, GND3, GND4, GND5: PTH 1.7mm
IDE_STM_A1, IDE_STM_A2, IDE_STM_A3, IDE_STM_A4, IDE_STM_A5: IDE STM A
IDE_STM_B1, IDE_STM_B2, IDE_STM_B3, IDE_STM_B4, IDE_STM_B5: IDE STM B cut
IDE_STM_C1, IDE_STM_C2, IDE_STM_C3, IDE_STM_C4, IDE_STM_C5: IDE STM C
IDE_STM_D1, IDE_STM_D2, IDE_STM_D3, IDE_STM_D4, IDE_STM_D5: IDE STM D cut
JPLed1, JPLed2, JPLed3, JPLed4, JPLed5: SolderJumper_3_Open; SolderJumper-3_P1.3mm_Open_RoundedPad1.0x1.5mm
JPReset1, JPReset2, JPReset3, JPReset4, JPReset5: SolderJumper_2_Open; SolderJumper-2_P1.3mm_Open_RoundedPad1.0x1.5mm
JPRscl1, JPRscl2, JPRscl3, JPRscl4, JPRscl5: SolderJumper_2_Open; SolderJumper-2_P1.3mm_Open_RoundedPad1.0x1.5mm
JPRsda1, JPRsda2, JPRsda3, JPRsda4, JPRsda5: SolderJumper_2_Open; SolderJumper-2_P1.3mm_Open_RoundedPad1.0x1.5mm
JPV1, JPV2, JPV3, JPV4, JPV5: SolderJumper_2_Open; SolderJumper-2_P1.3mm_Open_RoundedPad1.0x1.5mm
JPdn1, JPdn2, JPdn3, JPdn4, JPdn5: SolderJumper_2_Open; SolderJumper-2_P1.3mm_Open_RoundedPad1.0x1.5mm
JPdp1, JPdp2, JPdp3, JPdp4, JPdp5: SolderJumper_2_Open; SolderJumper-2_P1.3mm_Open_RoundedPad1.0x1.5mm
JPpuUSB1, JPpuUSB2, JPpuUSB3, JPpuUSB4, JPpuUSB5: SolderJumper_3_Open; SolderJumper-3_P1.3mm_Open_RoundedPad1.0x1.5mm
JPpuUSBconst1, JPpuUSBconst2, JPpuUSBconst3, JPpuUSBconst4, JPpuUSBconst5: SolderJumper_2_Open; SolderJumper-2_P1.3mm_Open_RoundedPad1.0x1.5mm
JPvbus1, JPvbus2, JPvbus3, JPvbus4, JPvbus5: SolderJumper_2_Open; SolderJumper-2_P1.3mm_Open_RoundedPad1.0x1.5mm
JSH1, JSH2, JSH3, JSH4, JSH5: PTH 1.7mm
JSL1, JSL2, JSL3, JSL4, JSL5: PTH 1.7mm
JVbat1, JVbat2, JVbat3, JVbat4, JVbat5: VBAT; TestPoint_THTPad_D1.0mm_Drill0.5mm
Jled1, Jled2, Jled3, Jled4, Jled5: PTH 1.7mm
JpuUSB1, JpuUSB2, JpuUSB3, JpuUSB4, JpuUSB5: PTH 1.7mm
Jrst1, Jrst2, Jrst3, Jrst4, Jrst5: PTH 1.7mm
L1, L2, L3, L4, L5: 100Ω@100MHz; L0805
LED1, LED2, LED3, LED4, LED5, LED6, LED7, LED8, LED9, LED10, LED11, LED12, LED13, LED14, LED15, LED16, LED17, LED18, LED19, LED20, LED21, LED22, LED23, LED24, LED25, LED26, LED27, LED28, LED29, LED30, LED31, LED32: WS2812B; LED-SMD_4P-L5.0-W5.0-TL-1
LED33, LED34, LED35, LED36, LED37: Green; LED0805-R-RD
LVssA1, LVssA2, LVssA3, LVssA4, LVssA5: 15-30nH; L0402
RGB1, RGB2, RGB3, RGB4, RGB5: LED WS2812B-S XL-5050RGBC; LED-SMD_4P-L5.0-W5.0-TL-1
RVbusI1, RVbusI2, RVbusI3, RVbusI4, RVbusI5: 51kΩ; R0402
RVbusO1, RVbusO2, RVbusO3, RVbusO4, RVbusO5: 100kΩ; R0402
Rled1, Rled2, Rled3, Rled4, Rled5: 1k-1.5k; R0402
Rpd1, Rpd2, Rpd3, Rpd4, Rpd5: 10kΩ; R0402
Rpu1, Rpu2, Rpu3, Rpu4, Rpu5: 10kΩ; R0402
RpuBoot1, RpuBoot2, RpuBoot3, RpuBoot4, RpuBoot5: 51kΩ; R0402
RpuUSB1, RpuUSB2, RpuUSB3, RpuUSB4, RpuUSB5: 1.5kΩ; R0402
Rscl1, Rscl2, Rscl3, Rscl4, Rscl5: 2.2kΩ; R0402
Rsda1, Rsda2, Rsda3, Rsda4, Rsda5: 2.2kΩ; R0402
SW1, SW2, SW3, SW4, SW5, SW6, SW7, SW8, SW9, SW10: Tactile Switch; SW-SMD_4P-L5.1-W5.1-P3.70-LS6.5-TL_H1.5
U1, U3, U5, U7, U9: 3.3V Voltage Regulator 200mA; SOT-23-3_L2.9-W1.6-P1.90-LS2.8-BR
U2, U4, U6, U8, U10: STM32F103C8T6; LQFP-48_L7.0-W7.0-P0.50-LS9.0-BL
USB1, USB2, USB3, USB4, USB5: USB_C; USB-C_SMD-TYPE-C-31-M-12
VSSA1, VSSA2, VSSA3, VSSA4, VSSA5: VSSA; TestPoint_THTPad_D1.0mm_Drill0.5mm
X1, X2, X3, X4, X5: Crystal 12MHz X322512MSB4SI; CRYSTAL-SMD_4P-L3.2-W2.5-BL

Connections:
+3.3V: 3.3V1.1, 3.3V2.1, 3.3V3.1, 3.3V4.1, 3.3V5.1, B1.3, B2.3, B3.3, B4.3, B5.3, C1.2, C2.2, C3.2, C4.2, C5.2, C6.2, C7.2, C8.2, C9.2, C10.2, C11.2, C12.2, C13.2, C14.2, C15.2, CVcc1.2, CVcc2.2, CVcc3.2, CVcc4.2, CVcc5.2, JPLed1.3 (B), JPLed2.3 (B), JPLed3.3 (B), JPLed4.3 (B), JPLed5.3 (B), JPRscl1.2 (B), JPRscl2.2 (B), JPRscl3.2 (B), JPRscl4.2 (B), JPRscl5.2 (B), JPRsda1.1 (A), JPRsda2.1 (A), JPRsda3.1 (A), JPRsda4.1 (A), JPRsda5.1 (A), JPV1.2 (B), JPV2.2 (B), JPV3.2 (B), JPV4.2 (B), JPV5.2 (B), JPpuUSBconst1.2 (B), JPpuUSBconst2.2 (B), JPpuUSBconst3.2 (B), JPpuUSBconst4.2 (B), JPpuUSBconst5.2 (B), LED1.1 (VDD), LED2.1 (VDD), LED3.1 (VDD), LED4.1 (VDD), LED5.1 (VDD), LED6.1 (VDD), LED7.1 (VDD), LED8.1 (VDD), LED9.1 (VDD), LED10.1 (VDD), LED11.1 (VDD), LED12.1 (VDD), LED13.1 (VDD), LED14.1 (VDD), LED15.1 (VDD), LED16.1 (VDD), LED17.1 (VDD), LED18.1 (VDD), LED19.1 (VDD), LED20.1 (VDD), LED21.1 (VDD), LED22.1 (VDD), LED23.1 (VDD), LED24.1 (VDD), LED25.1 (VDD), LED26.1 (VDD), LED27.1 (VDD), LED28.1 (VDD), LED29.1 (VDD), LED30.1 (VDD), LED31.1 (VDD), LED32.1 (VDD), LVssA1.2, LVssA2.2, LVssA3.2, LVssA4.2, LVssA5.2, RGB1.1 (VDD), RGB2.1 (VDD), RGB3.1 (VDD), RGB4.1 (VDD), RGB5.1 (VDD), Rpu1.2, Rpu2.2, Rpu3.2, Rpu4.2, Rpu5.2, RpuBoot1.1, RpuBoot2.1, RpuBoot3.1, RpuBoot4.1, RpuBoot5.1, SW2.2 (B), SW4.2 (B), SW6.2 (B), SW8.2 (B), SW10.2 (B), U1.3 (Vout), U2.23 (VSS_1), U2.35 (VSS_2), U2.47 (VSS_3), U3.3 (Vout), U4.23 (VSS_1), U4.35 (VSS_2), U4.47 (VSS_3), U5.3 (Vout), U6.23 (VSS_1), U6.35 (VSS_2), U6.47 (VSS_3), U7.3 (Vout), U8.23 (VSS_1), U8.35 (VSS_2), U8.47 (VSS_3), U9.3 (Vout), U10.23 (VSS_1), U10.35 (VSS_2), U10.47 (VSS_3)
/stm32pill1/Boot0: B2.2, RpuBoot2.2, U4.44 (BOOT0)
/stm32pill1/I2C1 SCL: IDE_STM_D2.SDA (IDE39_STM45), Rscl2.1, U4.45 (PB8)
/stm32pill1/I2C1 SDA: IDE_STM_D2.SCL (IDE37_STM46), Rsda2.1, U4.46 (PB9)
/stm32pill1/I2C2 SCL, USART3 TX: IDE_STM_B2.B1 (IDE24_STM13), U4.21 (PB10)
/stm32pill1/I2C2 SDA, USART3 RX: IDE_STM_B2.B0 (IDE22_STM14), U4.22 (PB11)
/stm32pill1/NRST: Crst2.2, JPReset2.1 (A), Jrst2.1, U4.7 (NRST)
/stm32pill1/OSC_IN: Cosc3.2, U4.5 (PD0-OSC_IN), X2.1 (OSC1)
/stm32pill1/OSC_OUT: Cosc4.2, U4.6 (PD1-OSC_OUT), X2.3 (OSC2)
/stm32pill1/SPI1 MISO: IDE_STM_B2.B6 (IDE38_STM3), U4.16 (PA6)
/stm32pill1/SPI1 MOSI: IDE_STM_B2.B5 (IDE36_STM4), U4.17 (PA7)
/stm32pill1/SPI1 SCK: IDE_STM_B2.B7 (IDE40_STM2), U4.15 (PA5)
/stm32pill1/SPI2 MISO: IDE_STM_A2.A5 (IDE14_STM17), U4.27 (PB14)
/stm32pill1/SPI2 MOSI: IDE_STM_A2.A4 (IDE12_STM18), U4.28 (PB15)
/stm32pill1/SPI2 NSS: IDE_STM_A2.A7 (IDE18_STM15), U4.25 (PB12)
/stm32pill1/SPI2 SCK: IDE_STM_A2.A6 (IDE16_STM16), U4.26 (PB13)
/stm32pill1/USART1 RX: IDE_STM_A2.A1 (IDE6_STM21), U4.31 (PA10)
/stm32pill1/USART1 TX: IDE_STM_A2.A2 (IDE8_STM20), U4.30 (PA9)
/stm32pill1/USB VBusSense: JPLed2.1 (A), JPvbus2.1 (A), RVbusI2.2, RVbusO2.1, U4.43 (PB7)
/stm32pill1/USBd+: JPdp2.2 (B), JPpuUSB2.3 (B), U4.33 (PA12), USB2.A6 (DP1), USB2.B6 (DP2)
/stm32pill1/USBd-: JPdn2.1 (A), JPpuUSB2.1 (A), U4.32 (PA11), USB2.A7 (DN1), USB2.B7 (DN2)
/stm32pill1/VBAT: JVbat2.1, U4.1 (VBAT)
/stm32pill1/VBUS: L2.1, RVbusI2.1, U3.2 (Vin)
/stm32pill1/VSSA: CVssA2.2, CVssAn2.2, LVssA2.1, U4.8 (VSSA), VSSA2.1
/stm32pill2/Boot0: B3.2, RpuBoot3.2, U6.44 (BOOT0)
/stm32pill2/I2C1 SCL: IDE_STM_D3.SDA (IDE39_STM45), Rscl3.1, U6.45 (PB8)
/stm32pill2/I2C1 SDA: IDE_STM_D3.SCL (IDE37_STM46), Rsda3.1, U6.46 (PB9)
/stm32pill2/I2C2 SCL, USART3 TX: IDE_STM_B3.B1 (IDE24_STM13), U6.21 (PB10)
/stm32pill2/I2C2 SDA, USART3 RX: IDE_STM_B3.B0 (IDE22_STM14), U6.22 (PB11)
/stm32pill2/NRST: Crst3.2, JPReset3.1 (A), Jrst3.1, U6.7 (NRST)
/stm32pill2/OSC_IN: Cosc5.2, U6.5 (PD0-OSC_IN), X3.1 (OSC1)
/stm32pill2/OSC_OUT: Cosc6.2, U6.6 (PD1-OSC_OUT), X3.3 (OSC2)
/stm32pill2/SPI1 MISO: IDE_STM_B3.B6 (IDE38_STM3), U6.16 (PA6)
/stm32pill2/SPI1 MOSI: IDE_STM_B3.B5 (IDE36_STM4), U6.17 (PA7)
/stm32pill2/SPI1 SCK: IDE_STM_B3.B7 (IDE40_STM2), U6.15 (PA5)
/stm32pill2/SPI2 MISO: IDE_STM_A3.A5 (IDE14_STM17), U6.27 (PB14)
/stm32pill2/SPI2 MOSI: IDE_STM_A3.A4 (IDE12_STM18), U6.28 (PB15)
/stm32pill2/SPI2 NSS: IDE_STM_A3.A7 (IDE18_STM15), U6.25 (PB12)
/stm32pill2/SPI2 SCK: IDE_STM_A3.A6 (IDE16_STM16), U6.26 (PB13)
/stm32pill2/USART1 RX: IDE_STM_A3.A1 (IDE6_STM21), U6.31 (PA10)
/stm32pill2/USART1 TX: IDE_STM_A3.A2 (IDE8_STM20), U6.30 (PA9)
/stm32pill2/USB VBusSense: JPLed3.1 (A), JPvbus3.1 (A), RVbusI3.2, RVbusO3.1, U6.43 (PB7)
/stm32pill2/USBd+: JPdp3.2 (B), JPpuUSB3.3 (B), U6.33 (PA12), USB3.A6 (DP1), USB3.B6 (DP2)
/stm32pill2/USBd-: JPdn3.1 (A), JPpuUSB3.1 (A), U6.32 (PA11), USB3.A7 (DN1), USB3.B7 (DN2)
/stm32pill2/VBAT: JVbat3.1, U6.1 (VBAT)
/stm32pill2/VBUS: L3.1, RVbusI3.1, U5.2 (Vin)
/stm32pill2/VSSA: CVssA3.2, CVssAn3.2, LVssA3.1, U6.8 (VSSA), VSSA3.1
/stm32pill3/Boot0: B4.2, RpuBoot4.2, U8.44 (BOOT0)
/stm32pill3/I2C1 SCL: IDE_STM_D4.SDA (IDE39_STM45), Rscl4.1, U8.45 (PB8)
/stm32pill3/I2C1 SDA: IDE_STM_D4.SCL (IDE37_STM46), Rsda4.1, U8.46 (PB9)
/stm32pill3/I2C2 SCL, USART3 TX: IDE_STM_B4.B1 (IDE24_STM13), U8.21 (PB10)
/stm32pill3/I2C2 SDA, USART3 RX: IDE_STM_B4.B0 (IDE22_STM14), U8.22 (PB11)
/stm32pill3/NRST: Crst4.2, JPReset4.1 (A), Jrst4.1, U8.7 (NRST)
/stm32pill3/OSC_IN: Cosc7.2, U8.5 (PD0-OSC_IN), X4.1 (OSC1)
/stm32pill3/OSC_OUT: Cosc8.2, U8.6 (PD1-OSC_OUT), X4.3 (OSC2)
/stm32pill3/SPI1 MISO: IDE_STM_B4.B6 (IDE38_STM3), U8.16 (PA6)
/stm32pill3/SPI1 MOSI: IDE_STM_B4.B5 (IDE36_STM4), U8.17 (PA7)
/stm32pill3/SPI1 SCK: IDE_STM_B4.B7 (IDE40_STM2), U8.15 (PA5)
/stm32pill3/SPI2 MISO: IDE_STM_A4.A5 (IDE14_STM17), U8.27 (PB14)
/stm32pill3/SPI2 MOSI: IDE_STM_A4.A4 (IDE12_STM18), U8.28 (PB15)
/stm32pill3/SPI2 NSS: IDE_STM_A4.A7 (IDE18_STM15), U8.25 (PB12)
/stm32pill3/SPI2 SCK: IDE_STM_A4.A6 (IDE16_STM16), U8.26 (PB13)
/stm32pill3/USART1 RX: IDE_STM_A4.A1 (IDE6_STM21), U8.31 (PA10)
/stm32pill3/USART1 TX: IDE_STM_A4.A2 (IDE8_STM20), U8.30 (PA9)
/stm32pill3/USB VBusSense: JPLed4.1 (A), JPvbus4.1 (A), RVbusI4.2, RVbusO4.1, U8.43 (PB7)
/stm32pill3/USBd+: JPdp4.2 (B), JPpuUSB4.3 (B), U8.33 (PA12), USB4.A6 (DP1), USB4.B6 (DP2)
/stm32pill3/USBd-: JPdn4.1 (A), JPpuUSB4.1 (A), U8.32 (PA11), USB4.A7 (DN1), USB4.B7 (DN2)
/stm32pill3/VBAT: JVbat4.1, U8.1 (VBAT)
/stm32pill3/VBUS: L4.1, RVbusI4.1, U7.2 (Vin)
/stm32pill3/VSSA: CVssA4.2, CVssAn4.2, LVssA4.1, U8.8 (VSSA), VSSA4.1
/stm32pill4/Boot0: B5.2, RpuBoot5.2, U10.44 (BOOT0)
/stm32pill4/I2C1 SCL: IDE_STM_D5.SDA (IDE39_STM45), Rscl5.1, U10.45 (PB8)
/stm32pill4/I2C1 SDA: IDE_STM_D5.SCL (IDE37_STM46), Rsda5.1, U10.46 (PB9)
/stm32pill4/I2C2 SCL, USART3 TX: IDE_STM_B5.B1 (IDE24_STM13), U10.21 (PB10)
/stm32pill4/I2C2 SDA, USART3 RX: IDE_STM_B5.B0 (IDE22_STM14), U10.22 (PB11)
/stm32pill4/NRST: Crst5.2, JPReset5.1 (A), Jrst5.1, U10.7 (NRST)
/stm32pill4/OSC_IN: Cosc9.2, U10.5 (PD0-OSC_IN), X5.1 (OSC1)
/stm32pill4/OSC_OUT: Cosc10.2, U10.6 (PD1-OSC_OUT), X5.3 (OSC2)
/stm32pill4/SPI1 MISO: IDE_STM_B5.B6 (IDE38_STM3), U10.16 (PA6)
/stm32pill4/SPI1 MOSI: IDE_STM_B5.B5 (IDE36_STM4), U10.17 (PA7)
/stm32pill4/SPI1 SCK: IDE_STM_B5.B7 (IDE40_STM2), U10.15 (PA5)
/stm32pill4/SPI2 MISO: IDE_STM_A5.A5 (IDE14_STM17), U10.27 (PB14)
/stm32pill4/SPI2 MOSI: IDE_STM_A5.A4 (IDE12_STM18), U10.28 (PB15)
/stm32pill4/SPI2 NSS: IDE_STM_A5.A7 (IDE18_STM15), U10.25 (PB12)
/stm32pill4/SPI2 SCK: IDE_STM_A5.A6 (IDE16_STM16), U10.26 (PB13)
/stm32pill4/USART1 RX: IDE_STM_A5.A1 (IDE6_STM21), U10.31 (PA10)
/stm32pill4/USART1 TX: IDE_STM_A5.A2 (IDE8_STM20), U10.30 (PA9)
/stm32pill4/USB VBusSense: JPLed5.1 (A), JPvbus5.1 (A), RVbusI5.2, RVbusO5.1, U10.43 (PB7)
/stm32pill4/USBd+: JPdp5.2 (B), JPpuUSB5.3 (B), U10.33 (PA12), USB5.A6 (DP1), USB5.B6 (DP2)
/stm32pill4/USBd-: JPdn5.1 (A), JPpuUSB5.1 (A), U10.32 (PA11), USB5.A7 (DN1), USB5.B7 (DN2)
/stm32pill4/VBAT: JVbat5.1, U10.1 (VBAT)
/stm32pill4/VBUS: L5.1, RVbusI5.1, U9.2 (Vin)
/stm32pill4/VSSA: CVssA5.2, CVssAn5.2, LVssA5.1, U10.8 (VSSA), VSSA5.1
/stm32pill/Boot0: B1.2, RpuBoot1.2, U2.44 (BOOT0)
/stm32pill/I2C1 SCL: IDE_STM_D1.SDA (IDE39_STM45), Rscl1.1, U2.45 (PB8)
/stm32pill/I2C1 SDA: IDE_STM_D1.SCL (IDE37_STM46), Rsda1.1, U2.46 (PB9)
/stm32pill/I2C2 SCL, USART3 TX: IDE_STM_B1.B1 (IDE24_STM13), U2.21 (PB10)
/stm32pill/I2C2 SDA, USART3 RX: IDE_STM_B1.B0 (IDE22_STM14), U2.22 (PB11)
/stm32pill/NRST: Crst1.2, JPReset1.1 (A), Jrst1.1, U2.7 (NRST)
/stm32pill/OSC_IN: Cosc1.2, U2.5 (PD0-OSC_IN), X1.1 (OSC1)
/stm32pill/OSC_OUT: Cosc2.2, U2.6 (PD1-OSC_OUT), X1.3 (OSC2)
/stm32pill/SPI1 MISO: IDE_STM_B1.B6 (IDE38_STM3), U2.16 (PA6)
/stm32pill/SPI1 MOSI: IDE_STM_B1.B5 (IDE36_STM4), U2.17 (PA7)
/stm32pill/SPI1 SCK: IDE_STM_B1.B7 (IDE40_STM2), U2.15 (PA5)
/stm32pill/SPI2 MISO: IDE_STM_A1.A5 (IDE14_STM17), U2.27 (PB14)
/stm32pill/SPI2 MOSI: IDE_STM_A1.A4 (IDE12_STM18), U2.28 (PB15)
/stm32pill/SPI2 NSS: IDE_STM_A1.A7 (IDE18_STM15), U2.25 (PB12)
/stm32pill/SPI2 SCK: IDE_STM_A1.A6 (IDE16_STM16), U2.26 (PB13)
/stm32pill/USART1 RX: IDE_STM_A1.A1 (IDE6_STM21), U2.31 (PA10)
/stm32pill/USART1 TX: IDE_STM_A1.A2 (IDE8_STM20), U2.30 (PA9)
/stm32pill/USB VBusSense: JPLed1.1 (A), JPvbus1.1 (A), RVbusI1.2, RVbusO1.1, U2.43 (PB7)
/stm32pill/USBd+: JPdp1.2 (B), JPpuUSB1.3 (B), U2.33 (PA12), USB1.A6 (DP1), USB1.B6 (DP2)
/stm32pill/USBd-: JPdn1.1 (A), JPpuUSB1.1 (A), U2.32 (PA11), USB1.A7 (DN1), USB1.B7 (DN2)
/stm32pill/VBAT: JVbat1.1, U2.1 (VBAT)
/stm32pill/VBUS: L1.1, RVbusI1.1, U1.2 (Vin)
/stm32pill/VSSA: CVssA1.2, CVssAn1.2, LVssA1.1, U2.8 (VSSA), VSSA1.1
GND: B1.1, B2.1, B3.1, B4.1, B5.1, C1.1, C2.1, C3.1, C4.1, C5.1, C6.1, C7.1, C8.1, C9.1, C10.1, C11.1, C12.1, C13.1, C14.1, C15.1, CVcc1.1, CVcc2.1, CVcc3.1, CVcc4.1, CVcc5.1, CVssA1.1, CVssA2.1, CVssA3.1, CVssA4.1, CVssA5.1, CVssAn1.1, CVssAn2.1, CVssAn3.1, CVssAn4.1, CVssAn5.1, Cosc1.1, Cosc2.1, Cosc3.1, Cosc4.1, Cosc5.1, Cosc6.1, Cosc7.1, Cosc8.1, Cosc9.1, Cosc10.1, Crst1.1, Crst2.1, Crst3.1, Crst4.1, Crst5.1, GND1.1, GND2.1, GND3.1, GND4.1, GND5.1, IDE_STM_A1.GND (IDE2_STM24), IDE_STM_A2.GND (IDE2_STM24), IDE_STM_A3.GND (IDE2_STM24), IDE_STM_A4.GND (IDE2_STM24), IDE_STM_A5.GND (IDE2_STM24), LED1.3 (GND), LED2.3 (GND), LED3.3 (GND), LED4.3 (GND), LED5.3 (GND), LED6.3 (GND), LED7.3 (GND), LED8.3 (GND), LED9.3 (GND), LED10.3 (GND), LED11.3 (GND), LED12.3 (GND), LED13.3 (GND), LED14.3 (GND), LED15.3 (GND), LED16.3 (GND), LED17.3 (GND), LED18.3 (GND), LED19.3 (GND), LED20.3 (GND), LED21.3 (GND), LED22.3 (GND), LED23.3 (GND), LED24.3 (GND), LED25.3 (GND), LED26.3 (GND), LED27.3 (GND), LED28.3 (GND), LED29.3 (GND), LED30.3 (GND), LED31.3 (GND), LED32.3 (GND), RGB1.3 (GND), RGB2.3 (GND), RGB3.3 (GND), RGB4.3 (GND), RGB5.3 (GND), RVbusO1.2, RVbusO2.2, RVbusO3.2, RVbusO4.2, RVbusO5.2, Rled1.1, Rled2.1, Rled3.1, Rled4.1, Rled5.1, Rpd1.1, Rpd2.1, Rpd3.1, Rpd4.1, Rpd5.1, SW1.3 (C), SW3.3 (C), SW5.3 (C), SW7.3 (C), SW9.3 (C), U1.1 (GND), U2.9 (VDDA), U2.24 (VDD_1), U2.36 (VDD_2), U2.48 (VDD_3), U3.1 (GND), U4.9 (VDDA), U4.24 (VDD_1), U4.36 (VDD_2), U4.48 (VDD_3), U5.1 (GND), U6.9 (VDDA), U6.24 (VDD_1), U6.36 (VDD_2), U6.48 (VDD_3), U7.1 (GND), U8.9 (VDDA), U8.24 (VDD_1), U8.36 (VDD_2), U8.48 (VDD_3), U9.1 (GND), U10.9 (VDDA), U10.24 (VDD_1), U10.36 (VDD_2), U10.48 (VDD_3), USB1.A1 (GND), USB1.A12 (GND), USB1.B1 (GND), USB1.B12 (GND), USB2.A1 (GND), USB2.A12 (GND), USB2.B1 (GND), USB2.B12 (GND), USB3.A1 (GND), USB3.A12 (GND), USB3.B1 (GND), USB3.B12 (GND), USB4.A1 (GND), USB4.A12 (GND), USB4.B1 (GND), USB4.B12 (GND), USB5.A1 (GND), USB5.A12 (GND), USB5.B1 (GND), USB5.B12 (GND), X1.2 (GND), X1.4 (GND), X2.2 (GND), X2.4 (GND), X3.2 (GND), X3.4 (GND), X4.2 (GND), X4.4 (GND), X5.2 (GND), X5.4 (GND)
unnamed: DI1.1, RGB1.4 (DI)
unnamed: DI2.1, RGB2.4 (DI)
unnamed: DI3.1, RGB3.4 (DI)
unnamed: DI4.1, RGB4.4 (DI)
unnamed: DI5.1, RGB5.4 (DI)
unnamed: IDE_STM_A1.A0 (IDE4_STM22), JPdn1.2 (B)
unnamed: IDE_STM_A1.A3 (IDE10_STM19), U2.29 (PA8)
unnamed: IDE_STM_A2.A0 (IDE4_STM22), JPdn2.2 (B)
unnamed: IDE_STM_A2.A3 (IDE10_STM19), U4.29 (PA8)
unnamed: IDE_STM_A3.A0 (IDE4_STM22), JPdn3.2 (B)
unnamed: IDE_STM_A3.A3 (IDE10_STM19), U6.29 (PA8)
unnamed: IDE_STM_A4.A0 (IDE4_STM22), JPdn4.2 (B)
unnamed: IDE_STM_A4.A3 (IDE10_STM19), U8.29 (PA8)
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

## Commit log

2024-11-08 hierachical schematic+pcb
    [OtterPill.kicad_pcb, OtterPill.kicad_sch, leds.kicad_pcb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]
2024-11-10 stm32pill schema
    [pillbus.kicad_pcb, pillbus.kicad_sch, stm32pill.kicad_pcb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]
2024-11-13 ide stm
    [OtterPill.kicad_pcb, OtterPill.kicad_sch, leds.kicad_sch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]
2024-11-17 stm32pill pcb
    [leds.kicad_pcb, pillbus.kicad_pcb, stm32pill.kicad_pcb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]
2024-11-20 added capacitor at volatage regulator input
    [bus.kicad_pcb, stm32pill.kicad_sch]
2024-11-21 improved layout
    [stm32pill.kicad_pcb, stm32pill.kicad_sch]
2024-11-22 changed layout of bus board
    [bus.kicad_pcb, stm32pill.kicad_pcb, stm32pill.kicad_sch]
2024-11-22 boot0: pullDown + serial resistor
    [bus.kicad_pcb, stm32pill.kicad_pcb, stm32pill.kicad_sch]
